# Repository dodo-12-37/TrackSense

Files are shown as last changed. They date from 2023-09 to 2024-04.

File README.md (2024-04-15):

# Avertissement :
> Ce Dépôt est un "Fork" du projet d'[origine](https://github.com/DFC-Informatique-Cegep-de-Sainte-Foy/TrackSense). Le projet d'origine risque d'être repris par les prochaines cohortes. Je veux garder des traces de notre projet dans l'état ou nous l'avons laissé à la fin du cours. Il y a aussi des chances que je le poursuive un jour.

# TrackSense 

> Le projet TrackSense est développé par des étudiants du programme [Techniques de l'informatique - Programmation, bases de données et serveurs - DEC accéléré](https://dfc.csfoy.ca/retourner-aux-etudes/programmes-a-temps-plein/informatique/techniques-de-linformatique-programmation-bases-de-donnees-et-serveurs-dec-accelere/) du cégep de Ste-Foy, dans le cadre de leur projet de synthèse de la session Automne 2023.

<p align="center">
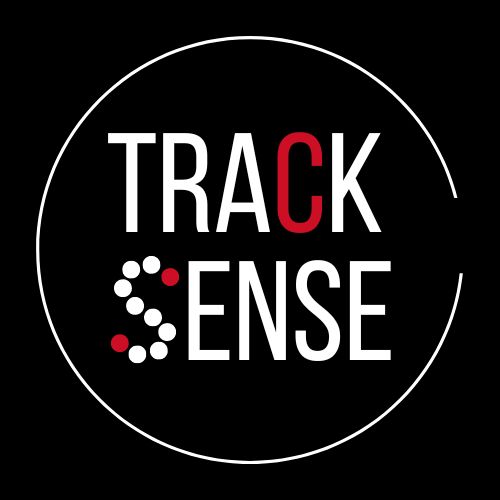
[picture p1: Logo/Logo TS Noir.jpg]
Logo_TrackSense
    
</p>

> - TrackSense est un boitier à fixer sur votre vélo pour enregistrer vos trajets.
> - L'application mobile permet la récupération, l'affichage et la sauvegarde des trajets. Elle sert également à la configuration du TrackSense.
> - L'API (serveur Web) est l'interface permettant de sauvegarder et récupérer les trajets.
> - La base de données sert à sauvegarder les données.

**Visionnez une démonstration sur youtube**

Youtube Video (https://youtu.be/xw6XdrmhHGA) 

<p align="center">
    Logo_TrackSense
</p>

> Le présent dépôt rassemble les informations générales et tout ce qui n'est pas du développement des applications (embarquée, mobile, Web, Base de données). Chaque application à son dépôt.

## Créer votre TrackSense !

> Pour garantir le bon fonctionnement de votre TrackSense, de sa communication avec votre application mobile et la sauvegarde de vos données, veuillez suivre les étapes [disponibles ici](https://github.com/DFC-Informatique-Cegep-de-Sainte-Foy/TrackSense/wiki) !

<p align="center">
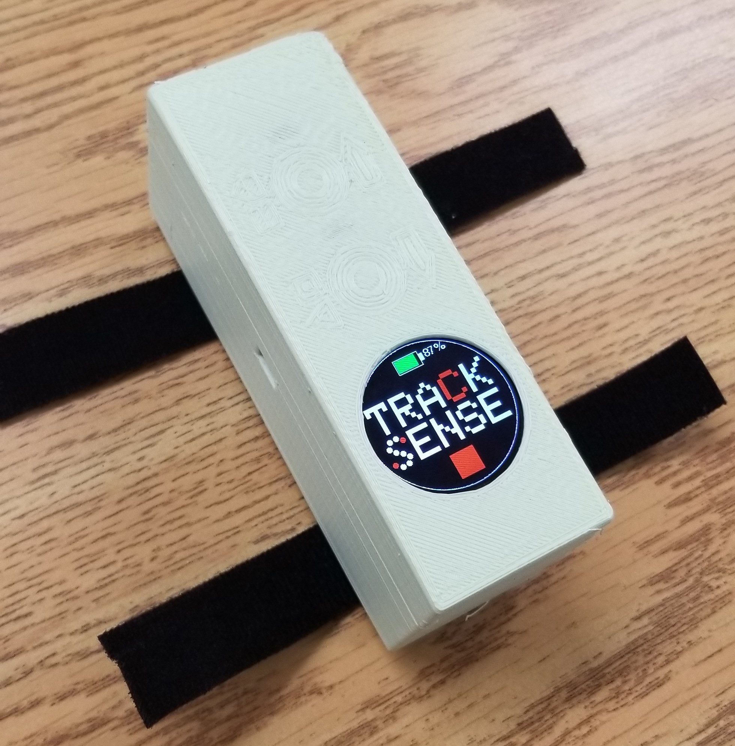
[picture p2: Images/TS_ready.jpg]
    
</p>

## Application embarquée

> L'application embarquée est le programme qui va s'exécuter à l'intérieur de votre TrackSense.
> Vous trouverez son dépôt GitHub [ici](https://github.com/DFC-Informatique-Cegep-de-Sainte-Foy/420-W57-SF_E23_4394_TrackSense_AppEmbarque).

<p align="center">
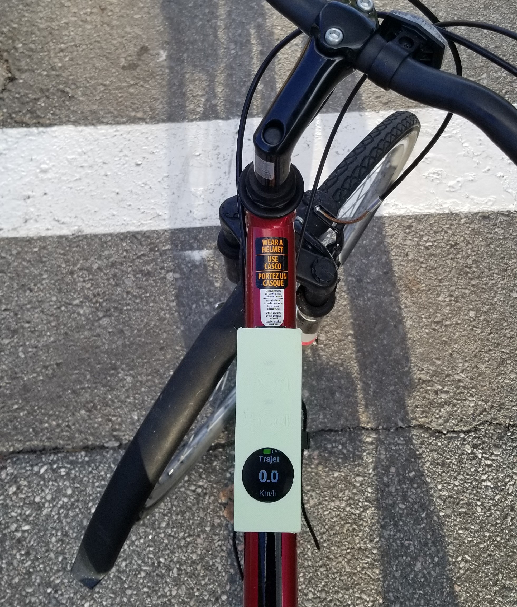
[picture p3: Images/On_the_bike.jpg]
    
</p>

## Application mobile

> L'application mobile est nécessaire pour configurer et communiquer avec votre TrackSense.
> Vous trouverez son dépôt GitHub [ici](https://github.com/DFC-Informatique-Cegep-de-Sainte-Foy/420-W57-SF_E23_4394_TrackSense_AppMobile).

<p align="center">
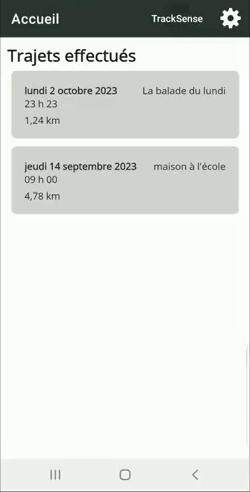
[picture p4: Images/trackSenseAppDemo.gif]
Logo_TrackSense
    
</p>

## Application Web (API)

> L'application Web est l'interface qui vous permet de communiquer avec votre base de données. Elle peut être hébergée en ligne ou chez vous.
> Vous trouverez son dépôt GitHub [ici](https://github.com/DFC-Informatique-Cegep-de-Sainte-Foy/420-W57-SF_E23_4394_TrackSense_ServeurWeb).

## Base de données

> La base de données est l'endroit où sont stockées vos données. Elle n'est accessible que via l'application Web.
> Vous trouverez son dépôt GitHub [ici](https://github.com/DFC-Informatique-Cegep-de-Sainte-Foy/420-W57-SF_E23_4394_TrackSense_BD).

## Manuel utilisateur

> Comment utiliser mon TrackSense ? Quelles sont les fonctionnalités ? Ça fait quoi quand j'appuie sur un bouton ?
> Pour avoir toutes les réponses à ces questions et bien d'autres, vous trouverez le manuel de l'utilisateur [ici](https://github.com/DFC-Informatique-Cegep-de-Sainte-Foy/TrackSense/wiki/Manuel) !  

## Informations générales

<p align="center">
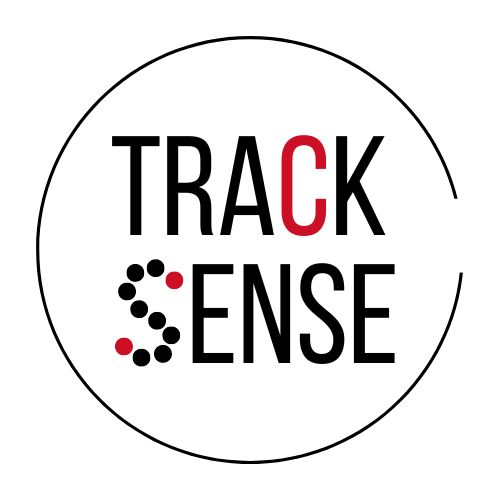
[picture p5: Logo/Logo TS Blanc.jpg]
Logo_TrackSense
    
</p>

> Quelques informations et/ou éléments supplémentaires :
> - [Logo](./TrackSense/tree/main/Logo/)
> - [Composants](./TrackSense/tree/main/Composants)

## Contributeurs

### Session été 2023

>-  [Dominique Lebrun](https://github.com/dodo-12-37)
>-  [Loïc Delas](https://github.com/LoicDelas)
>-  [Tien Binh Nguyen](https://github.com/binhnguyen84)
>-  [Simon Quillaud](https://github.com/simonquillaud)

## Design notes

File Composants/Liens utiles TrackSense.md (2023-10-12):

# Liste de liens utiles pour TrackSense

## Pièces achetées
- [TFT Display 1.28 Inch TFT LCD Display Module Round RGB 240*240 GC9A01 Driver 4 Wire SPI Interface 240x240 PCB For Arduino](https://www.aliexpress.com/item/1005004069703494.html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)
  - MEILLEUR LIEN : [**Using GC9A01 Round LCD Modules**](https://dronebotworkshop.com/gc9a01/)
  - [**Library Bodmer/TFT_eSPI**](https://github.com/Bodmer/TFT_eSPI/blob/master/User_Setups/Setup200_GC9A01.h)
  - [Library carlfriess/GC9A01_demo]()
  - [Exemple de code pour l'écran](https://www.makerfabs.com/gc9a01-1.28-inch-round-lcd-module.html)
  - [Adafruit_GC9A01A Library](https://github.com/adafruit/Adafruit_GC9A01A)  
  - [Adafruit GFX Library](https://github.com/adafruit/Adafruit-GFX-Library/blob/master/README.md)
  - [**ESP32 SPI Communication: Set Pins, Multiple SPI Bus Interfaces, and Peripherals (Arduino IDE)**](https://randomnerdtutorials.com/esp32-spi-communication-arduino/)
  - Exemple de code : [Photographic album using ESP32 and GC9A01 round screen](https://giltesa.com/en/2021/01/05/photographic-album-using-esp32-and-gc9a01-round-screen)
  - [Video : GC9A01 Round LCD with ESP32 & Arduino](https://www.youtube.com/watch?v=k2c2zCmC_X0)
  - Très bonne référence complète, mais pas modèle exacte [**Waveshare 1.28inch LCD Module**](https://www.waveshare.com/wiki/1.28inch_LCD_Module)
  - [**Waveshare : 240×240, General 1.28inch Round LCD Display Module, 65K RGB**](https://www.waveshare.com/1.28inch-LCD-Module.htm)
  - [**IPS LCD 1.28″ 240×240 RGB Round Display GC9A01**](https://protosupplies.com/product/ips-lcd-128-round-square-display-gc9a01-copy/)
  - [1.28inch LCD Display Module, IPS Screen, 65K RGB, 240 × 240 Resolution, SPI Interface. ](https://www.waveshare.com/wiki/1.28inch_LCD_Module#Introduction)
  - []()
  - []()
  - []()

- [LILYGO® TTGO T-SIM7000G 4MB / 16MB Module ESP32-WROVER-B Chip SIM Card WiFi Bluetooth 18650 Battery Holder Solar Charge Board](https://www.aliexpress.com/item/1005003094951052.html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)
  - [**Dépot GitHub Officiel LILYGO**](https://github.com/Xinyuan-LilyGO/LilyGO-T-SIM7000G)
  - [T-SIM7000G SIM Development Board ESP32 Wireless Module](https://www.lilygo.cc/products/t-sim7000g?variant=42275516776629)
  - [LILYGO® TTGO Accessories Shield LoRa 868/915 Mhz](https://www.tindie.com/products/lilygo/lilygo-ttgo-accessories-shield-lora-868915-mhz/)
  - [**ACOPTEX Guide to LILYGO T-SIM7000G ESP32 development board- AT communication**](https://acoptex.com/wp/guide-to-lilygo-t-sim7000g-esp32-development-board/)
  - [**LILYGO T-SIM7000G ESP32: Get GPS Data (Latitude, Longitude, Altitude, and more)**](https://randomnerdtutorials.com/lilygo-t-sim7000g-esp32-gps-data/)
  - [**Getting Started with LILYGO T-SIM7000G ESP32 (LTE, GPRS, and GPS)**](https://randomnerdtutorials.com/lilygo-t-sim7000g-esp32-lte-gprs-gps/)
  - [?? GNSS – How to use GNSS feature on Simcom Modules? ??](https://m2msupport.net/m2msupport/gnss-how-to-use-gnss-feature-on-simcom-modules/)
  - []()
  - []()
  - []()
  - [GSM/GPRS/GPS Shield (B), Arduino Shield Based on SIM808 ](https://www.waveshare.com/wiki/GSM/GPRS/GPS_Shield_(B))

- [GY-87 ou HW-290](https://fr.aliexpress.com/item/4000234539826.html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)
  - [Interfacing GY-87 IMU MPU6050 HMC5883L BMP085 Module with Arduino](https://electropeak.com/learn/interfacing-gy-87-10dof-imu-mpu6050-hmc5883l-bmp085-module-with-arduino/)
  - [HMC5883L_Simple Library](https://github.com/sleemanj/HMC5883L_Simple)
  - [GY-87 10DOF MPU6050 HMC5883L BMP180 Sensor Module](https://store.roboticsbd.com/sensors/382-gy-87-10dof-mpu6050-hmc5883l-bmp180-sensor-module-robotics-bangladesh.html)
  - [**Use and Calibrate HMC5883L Digital Compass**](https://www.best-microcontroller-projects.com/hmc5883l.html)
  - []()
  - []()
  - []()

- [MPU-6050]()
  - [**I2C Device Library** The I2C Device Library (i2cdevlib) is a collection of mostly uniform and well-documented classes to provide simple and intuitive interfaces to I2C devices.](https://github.com/jrowberg/i2cdevlib/tree/master/Arduino/MPU6050)
  - [MPU6050 by Electronic Cats - Library for Arduino](https://github.com/ElectronicCats/mpu6050/tree/master)
  - [What is MPU6050?](https://github.com/ElectronicCats/mpu6050/wiki/1.-What-is-MPU6050%3F#features)
  - [VIDEO : ESP32 Web Server with MPU-6050 Accelerometer and Gyroscope (3D object representation)](https://www.youtube.com/watch?v=dXcF-Uqa-gw)
  - []()
  - []()
  - []()

- [Buzzer SFM-27 ou SFM-20B](https://fr.aliexpress.com/item/1005001792688572.html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)
  - [Images dimension buzzer](https://fr.aliexpress.com/item/1005005426676025.html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,scm-url:1007.40050.281175.0,pvid:f82a8dd0-6433-49ed-a130-f7840a425f60,tpp_buckets:668%232846%238107%231934&pdp_npi=3%40dis%21CAD%210.58%210.52%21%21%21%21%21%402103250716890035395333740e7c3e%2112000033021292153%21rec%21CA%21)
  - []()
  - []()
  - []()

- [10 Pack TTP223B Digital Touch Capacitive Sensor Switch Module DIY for Arduino Raspberry Pi](https://www.aliexpress.com/item/1005004822891026.html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)
  - [Vidéo du fonctionnement des boutons](https://www.youtube.com/watch?v=V6ORKSxHLN0)
  - [Tutorial for TTP223 Touch Sensor Module ( Capacitive)](https://www.instructables.com/Tutorial-for-TTP223-Touch-Sensor-Module-Capacitive/)
  - Exemple avec capteur différent : [How to use a TTP223 based touch switch](https://diyusthad.com/2019/06/how-to-use-ttp223-based-touch-switch.html)
  - []()
  - []()
  - [CapacitiveSensor Library : CapacitiveSensor lets you create sensors that can detect touch or proximity.](https://github.com/PaulStoffregen/CapacitiveSensor)
  - [Capacitive Sensing Library](https://playground.arduino.cc/Main/CapacitiveSensor/)
  - [Vidéo explication : Capacitive Sensing Library](https://www.youtube.com/watch?v=jhtY_Hn5jBM)
  - []()
  - []()

- [Connecteur female headers PCB, long, 2.54mm, 11/12mm, 2mm, 3mm, 4mm, 6mm, 8mm, 10mm, 15mm, 20/40 broches](https://fr.aliexpress.com/item/1005003961219838.html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,scm-url:1007.40050.281175.0,pvid:3dd93779-9ecc-4d7b-9a69-51549ba19462,tpp_buckets:668%232846%238116%232002&pdp_npi=3%40dis%21CAD%211.65%211.65%21%21%21%21%21%402101ec1f16884816869006605eff6d%2112000027575194850%21rec%21CA%21)
  - [Dessin connecteurs female headers](https://fr.aliexpress.com/item/4000979967513.html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,scm-url:1007.40050.281175.0,pvid:e7105b2a-5874-40fd-b602-fba5c134012f,tpp_buckets:668%232846%238116%232002&pdp_npi=3%40dis%21CAD%211.0%210.95%21%21%21%21%21%402101ead816884800553916301ef787%2110000013144422244%21rec%21CA%21)
  - []()
  - []()
  - []()
  - []()
  - []()

## Tilt Compass
### Exemple avec bon capteurs (GY-87, MPU-6050, QMC5883L)
- [3 Axis Magnetometer Tilt Compensation](https://www.best-microcontroller-projects.com/magnetometer-tilt-compensation.html)
- [Vidéo Tilt Compensated Digital Compass based on AVR](https://www.youtube.com/watch?v=spmMMIMboPY)
- [Exemple GitHub visakhanc/eCompass](https://github.com/visakhanc/eCompass/blob/master/README.md)
- [Tutorial: How to use the GY-521 module (MPU-6050 breakout board) with the Arduino Uno](https://mschoeffler.com/2017/10/05/tutorial-how-to-use-the-gy-521-module-mpu-6050-breakout-board-with-the-arduino-uno/)
- []()
- []()
- []()
- []()
- []()

### Exemple avec mauvais capteurs
- [How to Use GY511 Module With Arduino [Make a Digital Compass]](https://www.instructables.com/How-to-Use-GY511-Module-With-Arduino-Make-a-Digita/)
- [Tilt Compensated Compass IvenSense MPU-9250 & MPU-6050 accelerometer / gyro & an AK8963 magnetometer](https://www.instructables.com/Tilt-Compensated-Compass/)
- []()
- []()
- []()
- []()
- []()
- []()
- []()
- []()

## Create PCB with EasyEDA Designer
- [Document Tutorial](https://docs.easyeda.com/en/Introduction/Schematic-Capture/index.html)
- [How to Make Custom ESP32 Board in 3 Hours | Full Tutorial](https://www.youtube.com/watch?app=desktop&v=S_p0YV-JlfU&feature=youtu.be)
- [Get quote for PCB - JLCPCB](https://cart.jlcpcb.com/quote)
- [Explication des connecteurs JST](https://www.mattmillman.com/info/crimpconnectors/common-jst-connector-types/#shsr)
- [Autre explication des connecteurs JST](https://www.ourpcb.com/jst-connector-types.html)
- []()
- []()
- []()
- []()
- []()
- []()

# Résumé 04 juillet

- [x] Ajouter 2ème rangée de pins pour connecter les CHEVELUS. 
- [x] Mesuré le speaker piézo et y trouver une place.
- [x] Ajouter un connecteur pour le speaker piézo.
- [x] Deux connectiques pour l'écran TFT. Un sur la TFCard et un sur le VSPI.
- [x] Ajouter deux connecteurs pour les boutons. (Vérifier pour une résistance???)
- [x] Ajouter des résistances pour les connecteurs I2C.
- [x] Enlever les connecteurs I2C en surplus.
- [x] Mettre le GY-87 directement sur le PCB.
- [x] Mettre des pins VCC et GND pour les boutons. (Et pins infos aussi ???)
- [ ] 

Fusion 360 fabriquer boitier

cd "C:\Program Files\Oracle\VirtualBox\"
VBoxManage.exe modifyvm "VM_MacOS_AppMobile_2" --cpuidset 00000001 000106e5 00100800 0098e3fd bfebfbff
VBoxManage setextradata "VM_MacOS_AppMobile_2" "VBoxInternal/Devices/efi/0/Config/DmiSystemProduct" "iMac19,3"
VBoxManage setextradata "VM_MacOS_AppMobile_2" "VBoxInternal/Devices/efi/0/Config/DmiSystemVersion" "1.0"
VBoxManage setextradata "VM_MacOS_AppMobile_2" "VBoxInternal/Devices/efi/0/Config/DmiBoardProduct" "Iloveapple"
VBoxManage setextradata "VM_MacOS_AppMobile_2" "VBoxInternal/Devices/smc/0/Config/DeviceKey" "ourhardworkbythesewordsguardedpleasedontsteal(c)AppleComputerInc"
VBoxManage setextradata "VM_MacOS_AppMobile_2" "VBoxInternal/Devices/smc/0/Config/GetKeyFromRealSMC" 0
VBoxManage setextradata "VM_MacOS_AppMobile_2" "VBoxInternal/TM/TSCMode" "RealTSCOffset"

Gravité	Code	Description	Projet	Fichier	Ligne	État de la suppression
Erreur	APT2098	xml_microsoft_maui_essentials_fileprovider_file_paths.xml.flat: error: failed to open file. "xml_microsoft_maui_essentials_fileprovider_file_paths.xml.flat: error: failed to open file.".	BluetoothLEConnection	C:\Program Files\dotnet\packs\Microsoft.Android.Sdk.Windows\32.0.485\tools\Xamarin.Android.Aapt2.targets	123

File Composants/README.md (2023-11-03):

# Composants

> Vous trouverez-ici l'ensemble des détails concernant les composants du TrackSense.

## Composants électroniques

## Boitier et visserie

> Le boitier actuel est à la version 1.0. Il a été conçu pour être imprimé en 3D. 
> Le boitier (couvercle, socle et btognau) à un poids d'environ 75g.
> Les plans sont disponibles aux formats suivants :
>   - dwg
>   - dxf
>   - f3d
>   - step

> L'ensemble de la visserie utilise du [filetage métrique M2](https://fr.wikipedia.org/wiki/Filetage_m%C3%A9trique#Pas_standard)
> - Quatre (4) tiges filetées : 
>    - &Oslash; : M2
>    - Longueur : 50 mm
> - Six (6) inserts filetés thermiques pour plastique :
>    - &Oslash; intérieur : M2
>    - &Oslash; extérieur : 3.5 mm
>    - Hauteur : 3 mm
> - Six (6) écrous de blocage :
>    - &Oslash; : M2
> - Deux (2) vis :
>    - &Oslash; : M2
>    - Longueur : 4 mm

## Estimation des coûts (2023)

> Voici des exemples de liens (non mis à jour) pour l'achat des composants ainsi qu'un prix **aproximatif** en dollar canadien.

| **Nom** | **Lien** | **Prix** |
| --- | --- | --- |
| Lilygo T-SIM7000G 16MB | [aliexpress](https://www.aliexpress.us/item/2255800356373344.html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) | 47.00$ |
| Écran GC9A01 | [aliexpress](https://www.aliexpress.us/item/3256803883388742.html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) | 4.00$ |
| Accéléromètre GY-87 | [aliexpress](https://www.aliexpress.us/item/2255800048225074.html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) | 4.00$ |
| Buzzer SFM-27 | [aliexpress](https://www.aliexpress.us/item/3256801606373820.html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) | 1.00$ |
| Boutons tactiles TTP223 | [aliexpress](https://fr.aliexpress.com/item/1005004822891026.html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) | 2.50$ |
| PCB | [JLCPCB](https://jlcpcb.com/) | 7.67$ |
| Connecteurs JST 4 pins (mâle et femelle) | [aliexpress](https://fr.aliexpress.com/item/4000120545240.html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) | 1.80$ |
| Connecteurs JST 8 pins (mâle et femelle) | [aliexpress](https://fr.aliexpress.com/item/4000120545240.html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) | 3.60$ |
| Connecteurs femelle 16 pins | [aliexpress](https://fr.aliexpress.com/item/1005003406780797.html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) | 1.50$ |
| Vis M2 | [aliexpress](https://fr.aliexpress.com/item/1005003083573172.html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) | 1.50$ |
| Écrous autobloquant M2 | [aliexpress](https://fr.aliexpress.com/item/4000075372035.html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) | 4.00$ |
| Inserts filetés M2 | [aliexpress](https://fr.aliexpress.com/item/1005003452792764.html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) | 5.00$ |
| Tiges fileteés M1 | [aliexpress](https://fr.aliexpress.com/item/1005001578222754.html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) | 7.00$ |
| Filament imprmante 3D | [aliexpress](https://fr.aliexpress.com/item/1005005581829928.html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) | 26.00$ |
| ---- | ---- | ---- |
| **Total** | --- | **116.57$** |

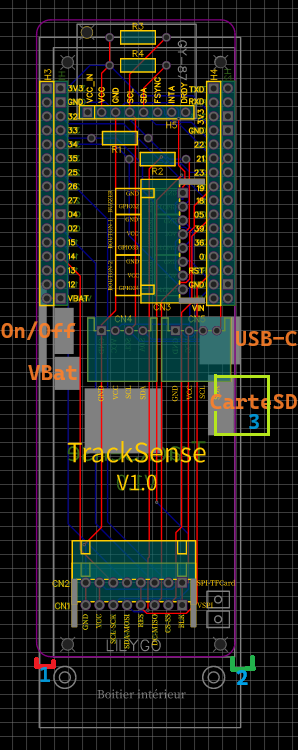
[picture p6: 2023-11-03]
Composants/PCB/V1.0/PCB_V1.0_AvecErreurDesign.png

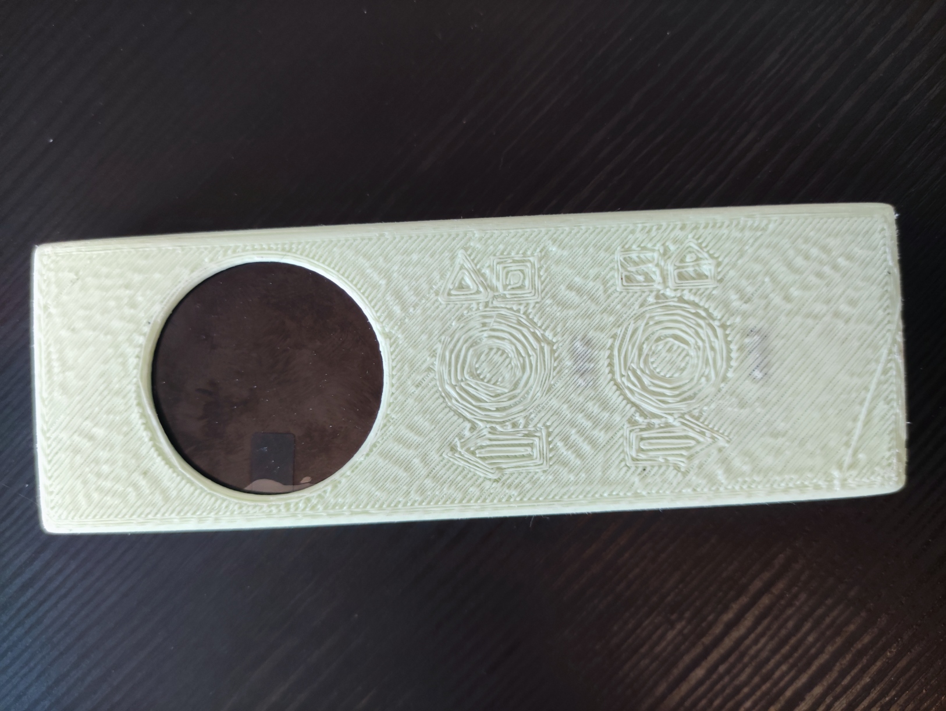
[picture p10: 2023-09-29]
Composants/Boitier/Photos_boitier/Couvercle 0.jpg

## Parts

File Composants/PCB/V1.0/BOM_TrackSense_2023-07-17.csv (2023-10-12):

ID | Name | Designator | Footprint | Quantity | Manufacturer Part | Manufacturer | Supplier | Supplier Part | Price | Pins | JLCPCB Part Class | Contributor | Package Display | Resistance | link
1 | S8B-XH-A-1(LF)(SN) | CN1,CN2,CN3 | CONN-TH_S8B-XH-A-1-LF-SN | 3 | S8B-XH-A-1(LF)(SN) | JST Sales America | LCSC | C495697 | 0.212 | 8 | Extended Part | LCSC
2 | S4B-XH-A (LF)(SN) | CN4,CN5 | CONN-TH_S4B-XH-A-LF-SN | 2 | S4B-XH-A(LF)(SN) | JST | LCSC | C157925 | 0.088 | 4 | Extended Part | LCSC
3 | KH-2.54PH180-1X16P-L11.5 | H1,H2,H3,H4 | HDR-TH_16P-P2.54-V-M | 4 | KH-2.54PH180-1X16P-L11.5 | kinghelm(金航标) | LCSC | C2905491 | 0.098 | 16 | Extended Part | LCSC
4 | KH-A2541HWV-8P | H5 | HDR-TH_8P-P2.54-V-F | 1 | KH-A2541HWV-8P | kinghelm(金航标) | LCSC | C2833314 | 0.209 | 8 | Extended Part | LCSC
5 | MFR-25FBF52-1K | R1,R2 | RES-TH_BD2.4-L6.3-P10.30-D0.6 | 2 | MFR-25FBF52-1K | YAGEO(国巨) | LCSC | C1364484 | 0.018 | 2 | Extended Part | lcsc | No | 1kΩ | https://atta.szlcsc.com/upload/public/pdf/source/20210730/C1364484_DDDEEE83E7C000729FE63E4A4E9762A5.pdf
6 | MFR-25FBF52-4.7K | R3,R4 | RES-TH_BD2.4-L6.3-P10.30-D0.6 | 2 | MFR-25FBF52-1K | YAGEO(国巨) | LCSC | C1364484 | 0.018 | 2 | Extended Part | lcsc | No | 1kΩ | https://atta.szlcsc.com/upload/public/pdf/source/20210730/C1364484_DDDEEE83E7C000729FE63E4A4E9762A5.pdf

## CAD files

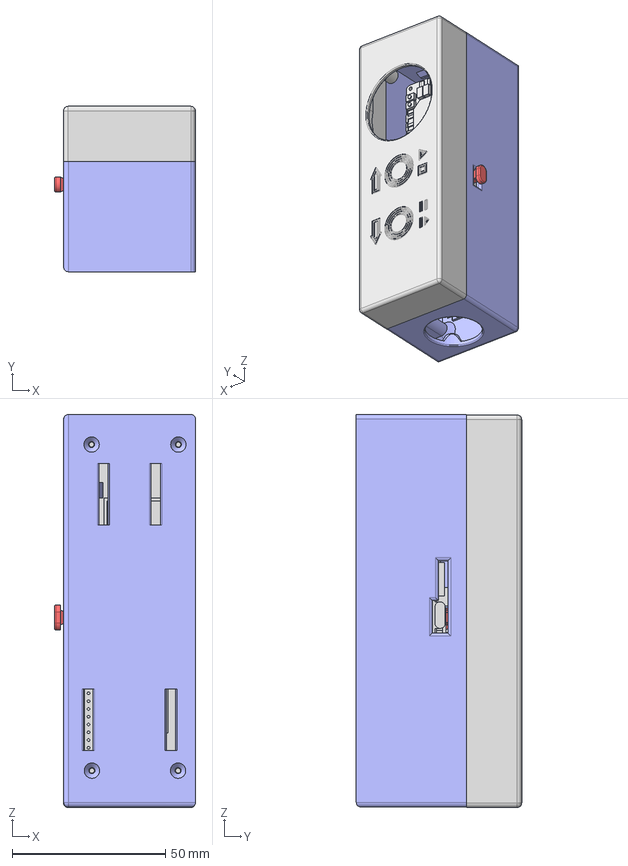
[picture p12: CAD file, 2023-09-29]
Composants/Boitier/V1.0/Boitier V1.0.step
46.0 x 54.0 x 128.2 mm
T-SIM7000G_6_08_
Couvercle
Bitognau

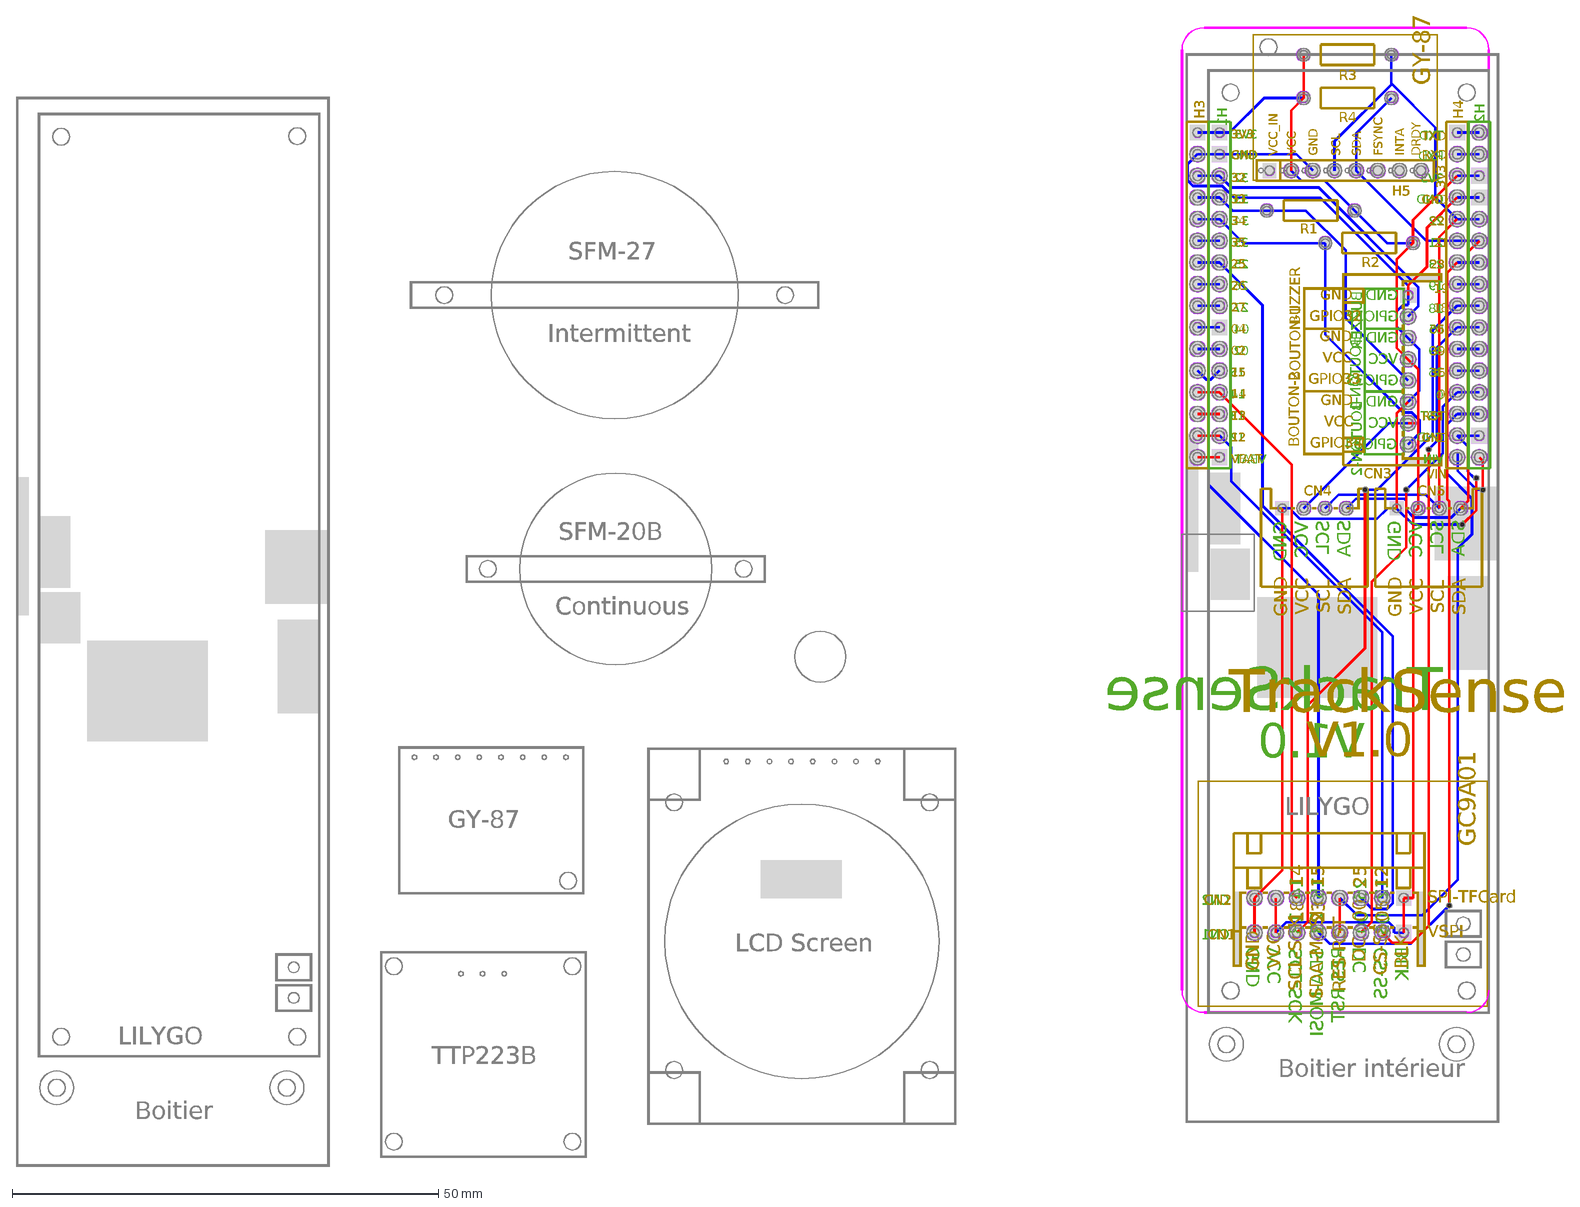
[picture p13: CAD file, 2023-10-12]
Composants/PCB/V1.0/PCB_TrackSense_Big_115.54X36mm_V1.0_2023-07-17.dxf
TrackSense
V1.0
3V3
GND
32
33
34
35
25
26
27
04
02
15
14
13
12
VBAT
VIN
RST
0
36
39
05
18
19
23
21
22
RXD
TXD
SDA
SCL
VCC
GPIO34
GPIO33
GPIO32
BUZZER
BOUTON-1
BOUTON-2
BLK
CS-SS
DC
RES-RST
SDA-MOSI
SCL-SCK
CN1
CN2
00
LILYGO
Boitier intérieur
TTP223B
GY-87
LCD Screen
Continuous
SFM-20B
Intermittent
SFM-27
Boitier
VCC_IN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

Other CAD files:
Composants/Boitier/V1.0/Boitier V1.0.dwg
Composants/Boitier/V1.0/Boitier V1.0.f3d

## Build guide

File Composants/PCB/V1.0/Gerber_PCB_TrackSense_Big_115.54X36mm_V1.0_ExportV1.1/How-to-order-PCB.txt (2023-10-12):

How to Order PCB

Please refer to:
https://docs.easyeda.com/en/PCB/Order-PCB

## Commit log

2023-09-29 Ajout photos et fichiers du boitier
    [Boitier V1.0.dwg, Boitier V1.0.f3d, Boitier V1.0.step]
2023-09-29 Assemblage boitier
2023-09-29 maj organisation fichiers boitier
    [Boitier V1.0.dwg, Boitier V1.0.f3d, Boitier V1.0.step]
2023-09-29 Ajout lien vers les photos du boitier
2023-10-12 Ajout lien vers Wiki pour la création du TrackSense
2023-10-12 Ajout README.md
    [Boitier V1.0.dwg, Boitier V1.0.f3d, Boitier V1.0.step]
2023-10-12 Ajout répertoires composants
    [BOM_TrackSense_2023-07-17.csv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]
2023-10-12 Ajouter .gitignore pour ignorer les modèles 3D
2023-11-03 Ajout de 2 images
2023-11-03 Corriger Prix PCB
